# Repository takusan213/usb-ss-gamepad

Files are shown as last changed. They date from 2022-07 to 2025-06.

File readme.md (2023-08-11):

# USB SS Gamepad
組み込み例

This project remakes your memorable SS Controller (aka Saturn pad) into a usb gamepad:video_game:  
Let's make a USB SS Gamepad and play retro games as well as recent games distributed on Steam. 

日本語のサポートページはこっち:crossed_flags:  
https://geekyfab.com/support_ss_gamepad  
You can read more details there.   

I also made a USB SFC(SNES) Gamepad [here](https://github.com/takusan213/usb-sfc-pad).  

# Demo
mario_play

# Features
In this project, I share circuit, BOM and firmware.  
I will share the PCB gerber data as soon as it is ready...  

You order your PCB with the gerber data, buy the materials on BOM, burn the firmware and assemble all, then you can get your USB SS Gamepad.
Though you need to use a driver and a soldering iron, it is fun and worth a try.

# PCB
編集後_部品面2_トリミング

編集後_ボタン面

# Tested OS / hardware
- Windows 10
- Windows 11
- Raspberry PI 3
    - Raspberry Pi OS 
    - Recalbox for RASPBERRY PI 3
    - RetroPi 4.7.1 for RASPBERRY PI 2/3
- Raspberry PI 4
    - Raspberry Pi OS
    - Recalbox for RASPBERRY PI 4/400
    - RetroPie 4.7.1 for RASPBERRY PI 4/400
- Retro Freak

# Usage
## Windows
In a Windows environment, USB SS Gamepad runs with standard driver.  
You don't need to install additional drivers.  

## Raspberry PI OS
In a Raspberry PI OS environment, you need to install 'joystick' package like this
```bash
sudo apt install joystick
```
It is also good to install 'jstest-gtk' for operation test.
```bash
sudo apt install jstest-gtk
```

## Recalbox and RetroPie
In Recalbox and RetroPie, you don't need to install 'joystick' package.  
Maybe Recalbox and RetroPie install it automatically.

# Manufacturing
To make a PCB you need to download the zipped gerber files and upload them to a PCB manufacturer like AllPCB.  
When you order the PCB, it is better to select "gold-plating" option so that conduction between pads of the PCB and rubber buttons of your suturn pad keep well.  
...Having said that, I also manufactured a "tin-plating" version and it just work in the beggining:clock1:  
(I sometimes felt that the "tin-plating" version didn't response.)
 
# Assembly
1. Remove the five screws and uncover your saturn pad.  
kumitate1

kumitate2

2. remove the original PCB and put in the USB SS Gamepad PCB.  
kumitate3

kumitate4

3. Cover the saturn pad and tighten the screws.  
kumitate5_2

# Author
* Takusan = [GEEKY Fab.](geekyfab.com)  
 
# License
The software files of "USB SS Gamepad" are under [Apache license 2.0](https://www.apache.org/licenses/LICENSE-2.0).  
The hardware files of "USB SS Gamepad" are under [CC BY-NC-SA 4.0](https://creativecommons.org/licenses/by-nc-sa/4.0/).

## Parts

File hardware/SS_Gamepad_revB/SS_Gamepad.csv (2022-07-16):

Reference | Quantity | Value | Footprint | Datasheet | Description | Height | Manufacturer_Name | Manufacturer_Part_Number | Mouser Part Number | Mouser Price/Stock | MPN | SKU
C101 | 1 | 0.1u | Capacitor_SMD:C_0402_1005Metric
C102 | 1 | 0.1u DNP | Capacitor_SMD:C_0402_1005Metric
C103 | 1 | 0.47u | Capacitor_SMD:C_0402_1005Metric
IC101 | 1 | PIC16F1459-I_SS | SamacSys_Parts:SOP65P780X200-20N | https://4donline.ihs.com/images/VipMasterIC/IC/MCHP/MCHPS05597/MCHPS05597-1.pdf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 | 8-bit Microcontrollers - MCU 14KB Fl 1kB R 48MHz Int. Oc 18 I0 | 2 | Microchip | PIC16F1459-I/SS | 579-PIC16F1459-I/SS | https://www.mouser.co.uk/ProductDetail/Microchip-Technology/PIC16F1459-I-SS?qs=PZkJWYMe7lds3WYNipntuQ%3D%3D
J101 | 1 | 53261-0671 | SamacSys_Parts:532610671 | https://www.molex.com/pdm_docs/sd/532610671_sd.pdf | 1.25mm Pitch, PicoBlade PCB Header, Single Row, Right-Angle, Surface Mount, Tin (Sn) Plating, Friction Lock, Circuits, Tape and Reel | 3.6 | Molex | 53261-0671 | 538-53261-0671 | https://www.mouser.co.uk/ProductDetail/Molex/53261-0671?qs=%252B72YyncTwW9Wyr77z4J2cA%3D%3D
J102 | 1 | HEADER_6P-2.54 | Connector_PinHeader_2.54mm:PinHeader_1x06_P2.54mm_Vertical |  |  |  |  |  |  |  | P125-1106A1BS116A1 | 320020078
JP101 JP102 | 2 | jumper pad | Jumper:SolderJumper-2_P1.3mm_Open_TrianglePad1.0x1.5mm
R101 R102 R103 R105 R106 R110 R113 R114 | 8 | 10k | Resistor_SMD:R_0603_1608Metric
R104 R107 R108 R109 R111 R112 | 6 | 10k DNP | Resistor_SMD:R_0603_1608Metric
SW101 SW102 SW103 SW104 SW105 SW106 SW107 SW108 SW109 SW110 SW111 | 11 | SW_Push | MyLibrary:SFC_Pad_F_NoSolder_5.5mm
SW112 SW113 | 2 | TL6110CF160QP | SamacSys_Parts:TL6110CF160QP | https://componentsearchengine.com/Datasheets/1/TL6110CF160QP.pdf | E-SWITCH - TL6110CF160QP - TACT SW, SPST-NO-DB, 0.05A, 12V, SOLDER | 8.25 | E-Switch | TL6110CF160QP | 612-TL6110CF | https://www.mouser.com/Search/Refine.aspx?Keyword=612-TL6110CF

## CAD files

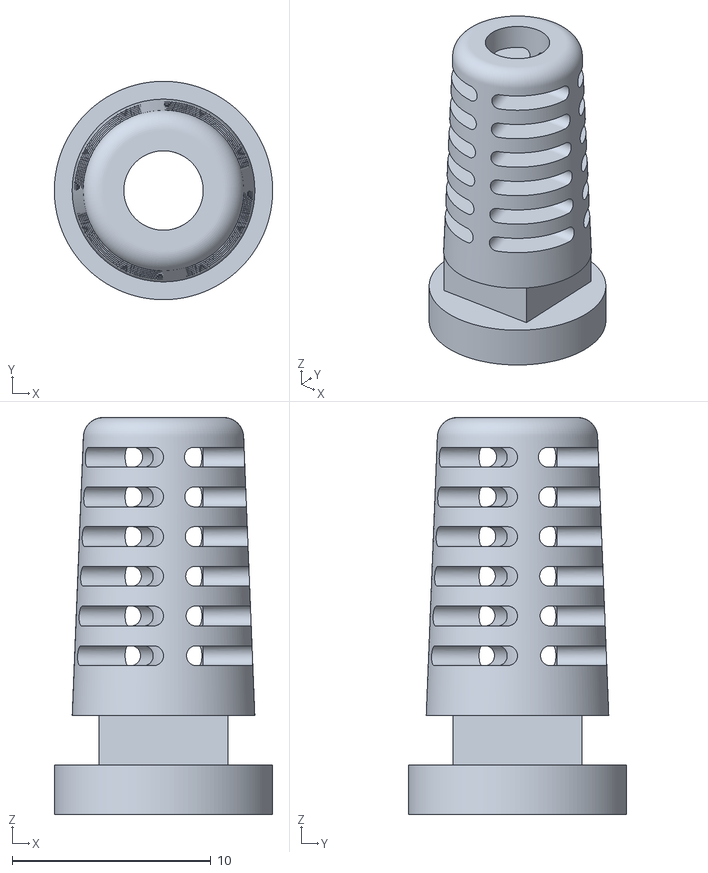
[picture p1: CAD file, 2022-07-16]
hardware/strain_relief/SS_Strain_Relief_ver2 v3.stl
11.0 x 11.0 x 20.0

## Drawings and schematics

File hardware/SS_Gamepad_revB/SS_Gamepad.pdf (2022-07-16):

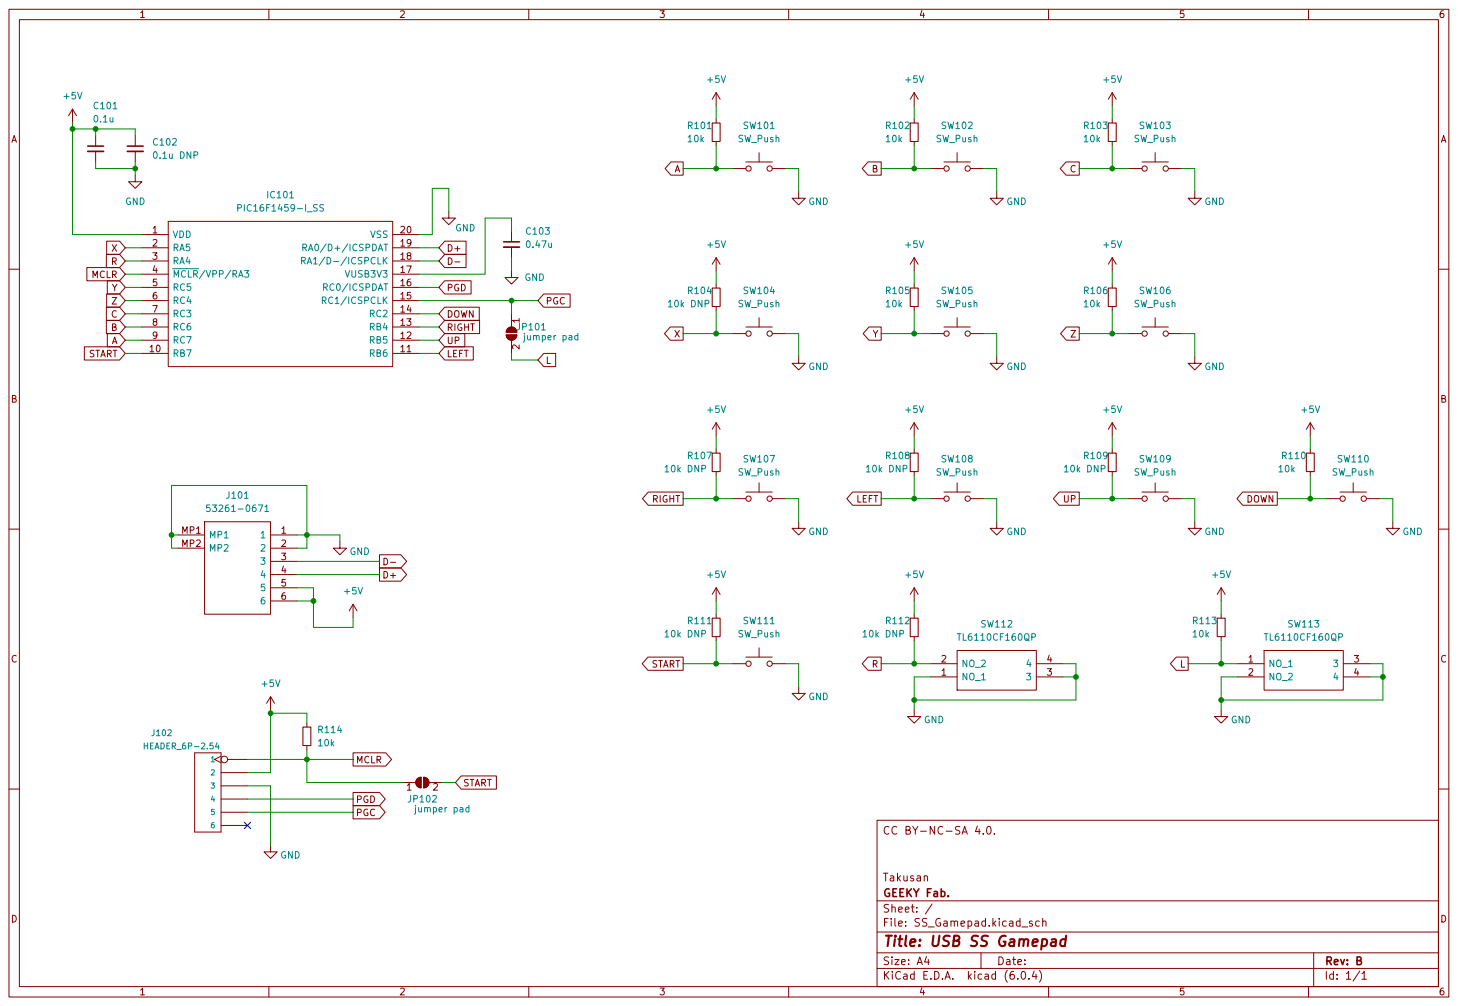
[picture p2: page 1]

File: SS_Gamepad.kicad_sch Sheet: / GEEKY Fab. Takusan CC BY-NC-SA 4.0.

Id: 1/1 Title: USB SS Gamepad

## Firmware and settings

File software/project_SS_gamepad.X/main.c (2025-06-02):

/*******************************************************************************
Copyright 2016 Microchip Technology Inc. (www.microchip.com)

Licensed under the Apache License, Version 2.0 (the "License");
you may not use this file except in compliance with the License.
You may obtain a copy of the License at

    http://www.apache.org/licenses/LICENSE-2.0

Unless required by applicable law or agreed to in writing, software
distributed under the License is distributed on an "AS IS" BASIS,
WITHOUT WARRANTIES OR CONDITIONS OF ANY KIND, either express or implied.
See the License for the specific language governing permissions and
limitations under the License.

To request to license the code under the MLA license (www.microchip.com/mla_license), 
please contact mla_licensing@microchip.com
*******************************************************************************/
/*********************************************************************
 * This file is modified by Geeky Fab.
 * 
 * Changes from the original source:
 *     - added device settings
 ********************************************************************/

/** INCLUDES *******************************************************/
#include "system.h"

#include "usb.h"
#include "usb_device_hid.h"

#include "app_device_joystick.h"
#include "mapping.h"



MAIN_RETURN main(void)
{
    SYSTEM_Initialize(SYSTEM_STATE_USB_START);

    USBDeviceInit();
    USBDeviceAttach();
    
    // Load button-to-usage mapping from High-Endurance Flash
    Mapping_Load();

    /* set all ports input*/
    TRISA = 0x30;
    TRISB = 0xf0;
    TRISC = 0xff;
    
    /* enabling internal pull up*/
    OPTION_REGbits.nWPUEN = 0;
    WPUA = 0x30;
    WPUB = 0x70;
    
    /* all ports used as degital ports.*/
    ANSELA = 0x00;
    ANSELB = 0x00;
    ANSELC = 0x00;
    
    /* initializing timer0 and interruption*/
    
    OPTION_REGbits.PS = 0b111;        // clock divided by 256
    OPTION_REGbits.PSA = 0;         // enabling prescaler
    OPTION_REGbits.TMR0SE = 0;      // edge select (rise)
    OPTION_REGbits.TMR0CS = 0;      // clock source select (internal)
    OPTION_REGbits.INTEDG = 1;      // interrupt edge select (rise)
//    INTCONbits.TMR0IF = 0;          // reset timer0 interrupt flag
//    INTCONbits.TMR0IE = 1;          // enabling peripheral interrupts
    INTCONbits.GIE = 1;             // enabling interrupts
    
    // setting initial value of timer 0.
    // 1 clock = 256/16MHz = 16us 
    // the timer interrupt happens every 16us x 0xff(255) = 4080us .
    // 
    // set the timer0 value so that timer interruption happens every 4000us.
    // 80us / 16us = 5 clocks
    TMR0bits.TMR0 = (uint8_t)5;
    
    
    while(1)
    {
        SYSTEM_Tasks();

        #if defined(USB_POLLING)
            // Interrupt or polling method.  If using polling, must call
            // this function periodically.  This function will take care
            // of processing and responding to SETUP transactions
            // (such as during the enumeration process when you first
            // plug in).  USB hosts require that USB devices should accept
            // and process SETUP packets in a timely fashion.  Therefore,
            // when using polling, this function should be called
            // regularly (such as once every 1.8ms or faster** [see
            // inline code comments in usb_device.c for explanation when
            // "or faster" applies])  In most cases, the USBDeviceTasks()
            // function does not take very long to execute (ex: <100
            // instruction cycles) before it returns.
            USBDeviceTasks();
        #endif

        /* If the USB device isn't configured yet, we can't really do anything
         * else since we don't have a host to talk to.  So jump back to the
         * top of the while loop. */
        if( USBGetDeviceState() < CONFIGURED_STATE )
        {
            /* Jump back to the top of the while loop. */
            continue;
        }

        /* If we are currently suspended, then we need to see if we need to
         * issue a remote wakeup.  In either case, we shouldn't process any
         * keyboard commands since we aren't currently communicating to the host
         * thus just continue back to the start of the while loop. */
        if( USBIsDeviceSuspended() == true )
        {
            /* Jump back to the top of the while loop. */
            continue;
        }

        //Application specific tasks
        APP_DeviceJoystickTasks();

    }//end while
}//end main

/*******************************************************************************
 End of File
*/

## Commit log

2023-07-15 [add] release binary for switch
2025-06-02 [add] HID Feature Report for host-driven button mapping and NVM persistence (WIP, contains known issues)
    - Add Feature Report (ID 0x02) in usb_descriptors.c to let the host application configure button mappings via HID Set_Report
    - Implement Mapping_Load() and Mapping_Save() to store the mapping table in non-volatile flash (HEF/NVM)
    - Update usb_config.h to hook into the SET_REPORT handler and enable NVM support
    - **Work in progress: known bugs still present**
    [main.c]
2025-06-02 [add] dual HID interface for Gamepad and Vendor Mapping (in progress, errors remain)
    - Refactored USB descriptors to define two HID interfaces:
    - Interface 0: Standard Gamepad HID (no Report ID, for DirectInput)
    - Interface 1: Vendor-specific HID for mapping configuration (Report ID 1, Feature report, for WebHID)
    - Added separate HID report descriptors and updated configuration descriptor accordingly
    - Updated usb_device_hid.c to handle GET_DESCRIPTOR requests for both interfaces and return the correct report descriptor
    - Updated mapping.c/h to support Feature report transfer for button mapping
    - Fixed endpoint and interface configuration, and adjusted power attributes
    - Increased US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
2025-06-02 Almost fully working — just a bit more tweaking left
2025-06-02 fix: reserve HEF region (0x1F80–0x1FFF) via linker and zero-pad unused HEF area for safe writes
    - Exclude 0x1F80–0x1FFF from code placement using XC8 linker ROM ranges
    - Add zero-padding to remaining bytes in HEF row buffer before calling FLASH_RowWrite
2025-06-02 [feat] Add SET_REPORT handling for mapping write via feature report
    - Implemented SET_REPORT reception using USBEP0Receive with callback
    - Mapping is now written to HEF upon receiving feature report
    - Verified that write succeeds and correct data can be read back immediately
    - Issue remains: mapping is not retained after power cycle (load from HEF may be failing)
2025-06-02 feat(mapping): persist custom button map across power cycles
    - Correctly pack/unpack 14-bit flash words in map_to_rowbuf and Mapping_Load
    - Verified mapping writes are retained after reboot
    - Note: mapping now loads correctly but isn’t yet applied to button input handling
2025-06-02 feat: fully enable runtime button-mapping via web app
    * Implement phys→usage look-up with table and Mapping_GetUsage()
    * Store mapping in HEF, load once at boot; retained across power cycles
    * Fixed Z/L/R button ghosting by one-to-one phys pin map
    * Web configurator can now write/read mapping and gamepad reflects changes
2025-07-01 implement dual-mode button mapping with Start+R toggle
2025-07-20 [add] release fw version 2.0.0 for direct input and switch.
